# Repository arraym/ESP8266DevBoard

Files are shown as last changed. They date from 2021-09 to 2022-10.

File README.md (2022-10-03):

# **ESP8266DevBoard v1.1**

## Programming interface

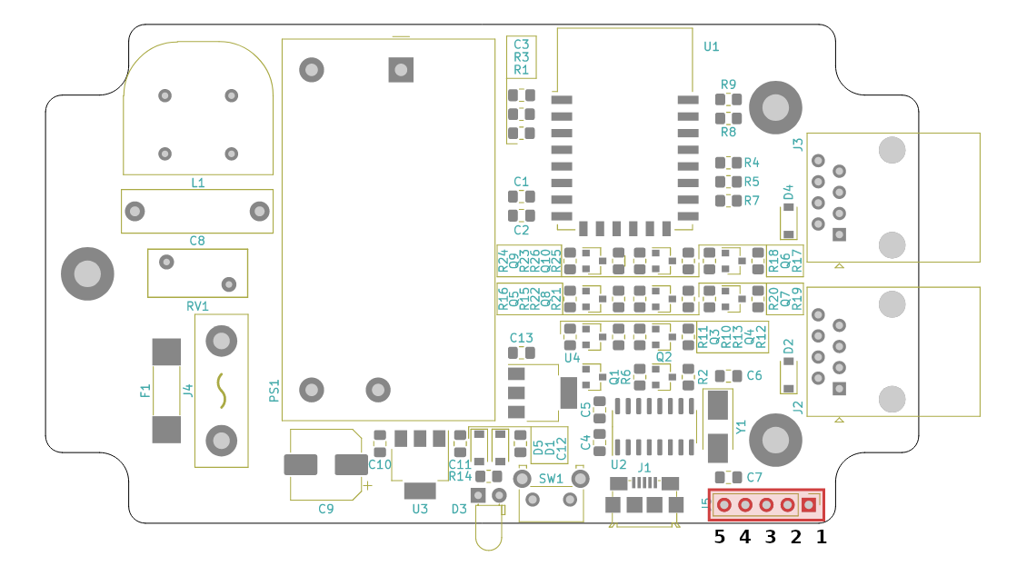
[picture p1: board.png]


The Serial UART interface is available at `J5` with the following pinout:

| Board Pin# | Signal | Required |
| --- | --- | --- |
| 1 | DTR | YES |
| 2 | RX | YES |
| 3 | TX | YES |
| 4 | RTS | YES |
| 5 | GND | YES |

For programming, all the pins marked as required must be connected.

**Remember to connect RX signal of the board to the RX signal of the programmer (same for TX).**

## Changelog

### **Changelog v1.1** ##
* J2, J3 (China RJ11 connectors) changed with RJ45 (MTJ-881X1)
* new LED and buzzer 12V controll lines added on each RJ45 connector

### **Changelog v1.2** ##
* J5 programming connector added (68001-420HLF)
* U2, Y1, C4, C5, C6, C7, D1, J1 set to DNP

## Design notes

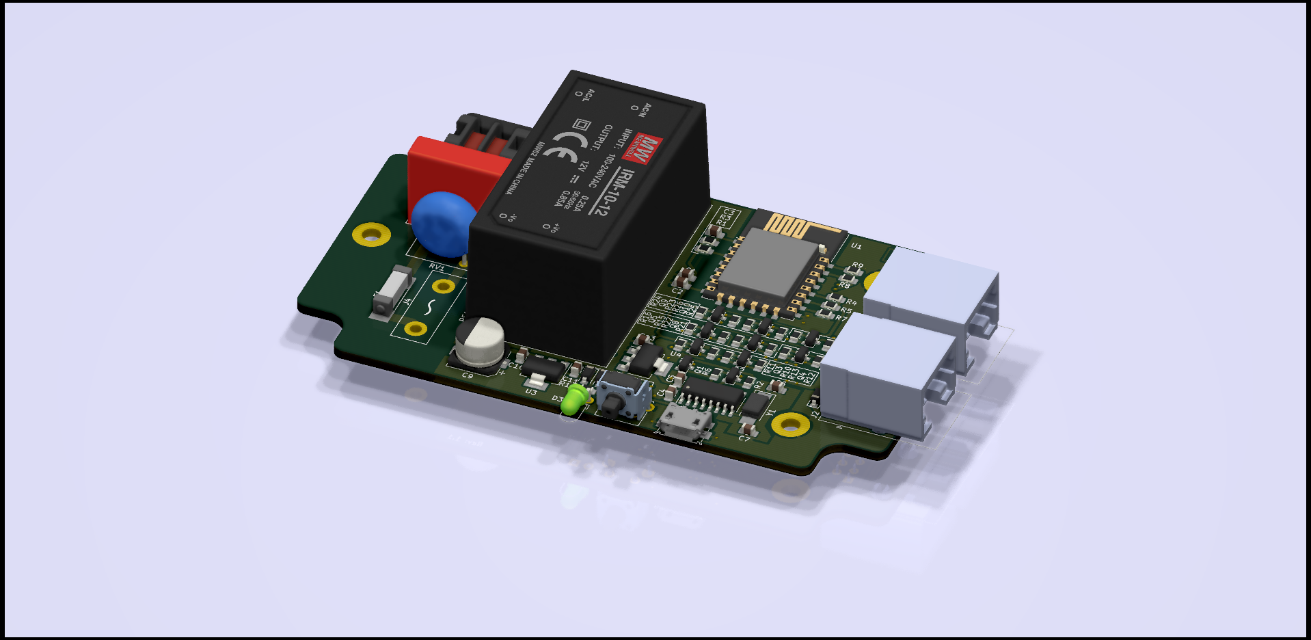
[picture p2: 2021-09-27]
ESP8266DevBoard.png

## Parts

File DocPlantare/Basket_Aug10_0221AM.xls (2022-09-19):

SHOPPING BASKET
This is not an invoice
10-Aug-21 02:21:33
 | Mouser No | Mfr. No | Manufacturer | Customer No | Description | RoHS | Lifecycle | Order Qty. | Price (RON) | Ext.: (RON)
1 | 647-UWX0J221MCL1 | UWX0J221MCL1GB | Nichicon |  | Aluminium Electrolytic Capacitors - SMD 6.3volts 220uF AEC-Q200 | RoHS Compliant |  | 6 | 1,56 RON | 9,36 RON
2 | 652-CR0805JW-471ELF | CR0805-JW-471ELF | Bourns |  | Thick Film Resistors - SMD 470ohm 5% | RoHS Compliant By Exemption |  | 20 | 0,092 RON | 1,84 RON
3 | 81-GRM21BC81C106KE5L | GRM21BC81C106KE15L | Murata |  | Multilayer Ceramic Capacitors MLCC - SMD/SMT 0805 10uF 16volts *Derate Voltage/Temp | RoHS Compliant |  | 25 | 0,737 RON | 18,43 RON
4 | 621-1N5819HWQ-7-F | 1N5819HWQ-7-F | Diodes Incorporated |  | Schottky Diodes & Rectifiers Schottky Rectifier | RoHS Compliant |  | 25 | 1,36 RON | 34,00 RON
5 | 815-ABM3-12-D2Y-T | ABM3-12.000MHZ-D2Y-T | ABRACON |  | Crystals 12.0 MHZ 18PF 60OHM | RoHS Compliant By Exemption |  | 6 | 2,71 RON | 16,26 RON
6 | 652-MOV-10D561K | MOV-10D561K | Bourns |  | Varistors 180pF 560volts 10% | RoHS Compliant |  | 6 | 0,698 RON | 4,19 RON
7 | 863-BC847BLT1G | BC847BLT1G | ON Semiconductor |  | Bipolar Transistors - BJT 100mA 50V NPN | RoHS Compliant |  | 12 | 0,587 RON | 7,04 RON
8 | 649-10118192-0001LF | 10118192-0001LF | FCI / Amphenol |  | USB Connectors 5P MICRO USB TYPE B RECEPTACLE | RoHS Compliant |  | 6 | 1,77 RON | 10,62 RON
9 | 80-C0805C104M5R | C0805C104M5RACTU | KEMET |  | Multilayer Ceramic Capacitors MLCC - SMD/SMT 50V 0.1uF X7R 0805 20% | RoHS Compliant |  | 30 | 0,16 RON | 4,80 RON
10 | 80-C0805C180M3HACTU | C0805C180M3HACTU | KEMET |  | Multilayer Ceramic Capacitors MLCC - SMD/SMT 25V 18pF X8R 0805 20% | RoHS Compliant |  | 12 | 0,31 RON | 3,72 RON
11 | 652-CR0805-JW-103ELF | CR0805-JW-103ELF | Bourns |  | Thick Film Resistors - SMD 10K 5% | RoHS Compliant By Exemption |  | 100 | 0,039 RON | 3,90 RON
12 | 80-SU9H-01100 | SU9H-01100 | KEMET |  | Common Mode Chokes / Filters 0.1amp 10mH | RoHS Compliant |  | 6 | 3,57 RON | 21,42 RON
13 | 693-3405.0165.24 | 3405.0165.24 | Schurter |  | Surface Mount Fuses UMF 250, 800mA 250 VAC, 125 VDC | RoHS Compliant |  | 6 | 2,71 RON | 16,26 RON
14 | 709-IRM10-12 | IRM-10-12 | MEAN WELL |  | AC/DC Power Modules 12V 0.85A 10.2W 85-264Vin Encap PS | RoHS Compliant |  | 3 | 38,07 RON | 114,21 RON
15 | 653-B3F-3152 | B3F-3152 | Omron |  | Tactile Switches R/A 6X6 6.15mm BTN | RoHS Compliant |  | 5 | 2,01 RON | 10,05 RON
16 | 863-LM1117MPX-33NOPB | LM1117MPX-33NOPB | ON Semiconductor |  | LDO Voltage Regulators LM ANA SOT223 800MA LDO |  | New Product | 6 | 2,43 RON | 14,58 RON
17 | 863-LM1117MPX-50NOPB | LM1117MPX-50NOPB | ON Semiconductor |  | LDO Voltage Regulators LM ANA SOT223 800MA LDO |  | New Product | 6 | 2,43 RON | 14,58 RON
18 | 485-2491 | 2491 | Adafruit |  | WiFi Development Tools - 802.11 ESP8266 SMT Module - ESP-12F | RoHS Compliant |  | 5 | 28,62 RON | 143,10 RON
19 | 726-2N7002H6327XTSA2 | 2N7002H6327XTSA2 | Infineon |  | MOSFET N-Ch 60V 300mA SOT-23-3 | RoHS Compliant |  | 25 | 0,912 RON | 22,80 RON
20 | 859-LTL-4231N | LTL-4231N | Lite-On |  | Standard LEDs - Through Hole Green Diffused | RoHS Compliant |  | 10 | 0,403 RON | 4,03 RON
21 | 80-R46KI310000M1K | R46KI310000M1K | KEMET |  | Safety Capacitors 275vac 0.1uF 10% | RoHS Compliant |  | 6 | 1,77 RON | 10,62 RON
By submitting your order you agree to these terms and conditions. (https://ro.mouser.com/saleterms) |  |  |  |  |  |  |  |  | Merchandise: | 485,81 RON
Prices are reflected at the date and time shown. |  |  |  |  |  |  |  |  | Delivery Charge: | 0,00 RON

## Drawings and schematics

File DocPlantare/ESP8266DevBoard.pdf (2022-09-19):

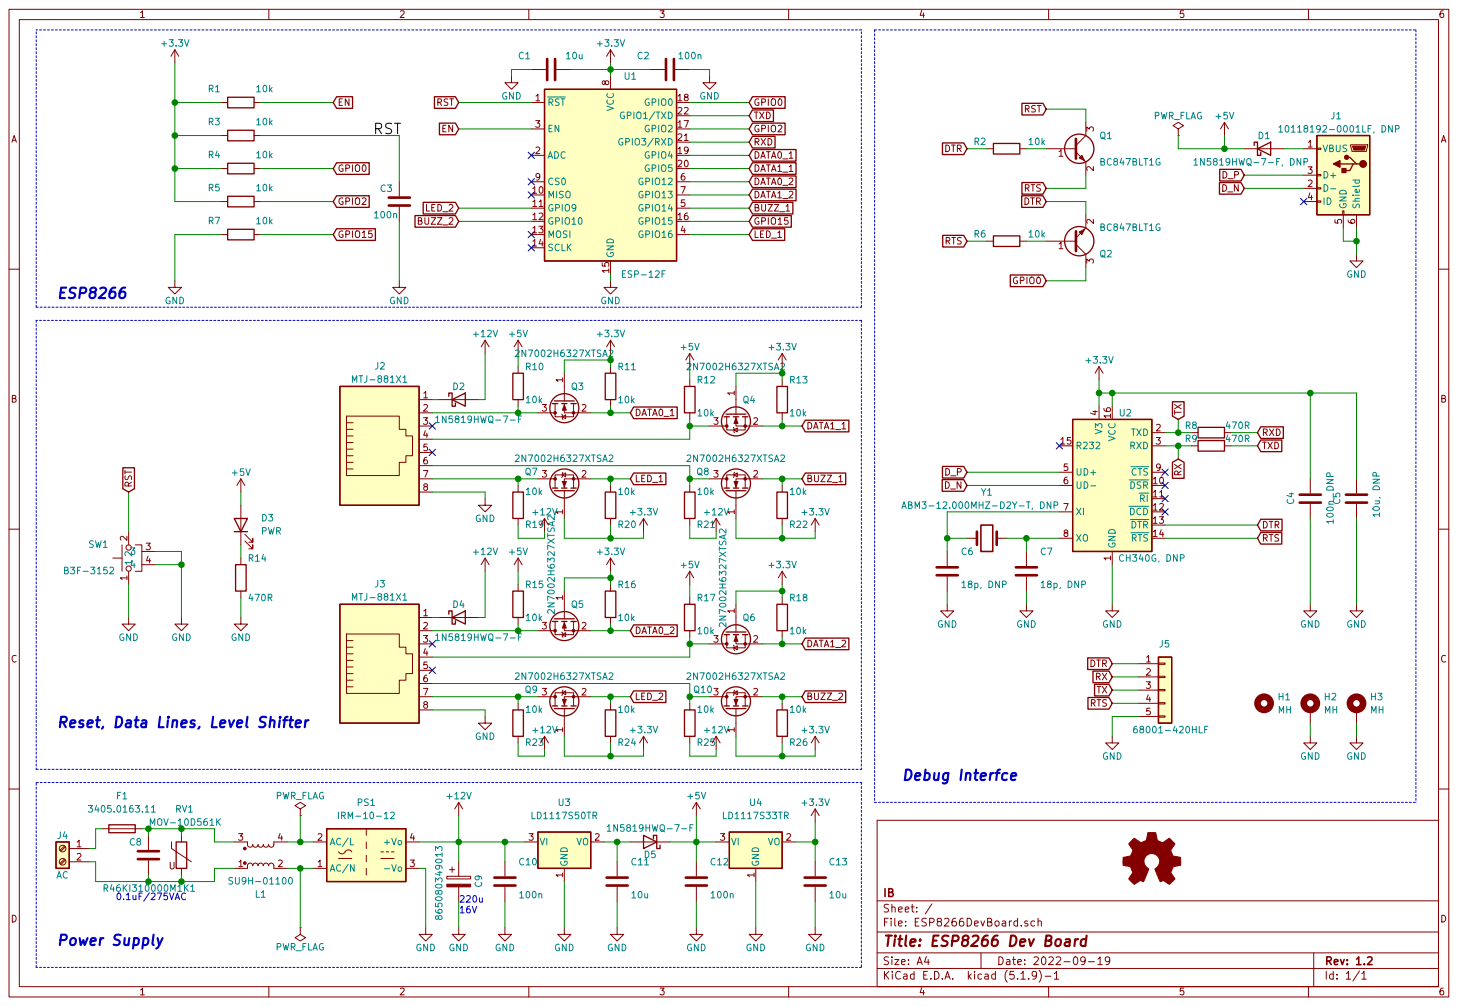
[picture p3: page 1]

1 DSR 10 RI 11 DCD 12 DTR 13 RTS 14 R232 15 VCC 16 TXD 2 RXD 3 V3

4 UD+ 5 UD- 6 XI 7 XO 8 CTS 9 U2CH340G, DNP

Reset, Data Lines, Level Shifter

File: ESP8266DevBoard.sch Sheet: /
Id: 1/1 Title: ESP8266 Dev Board

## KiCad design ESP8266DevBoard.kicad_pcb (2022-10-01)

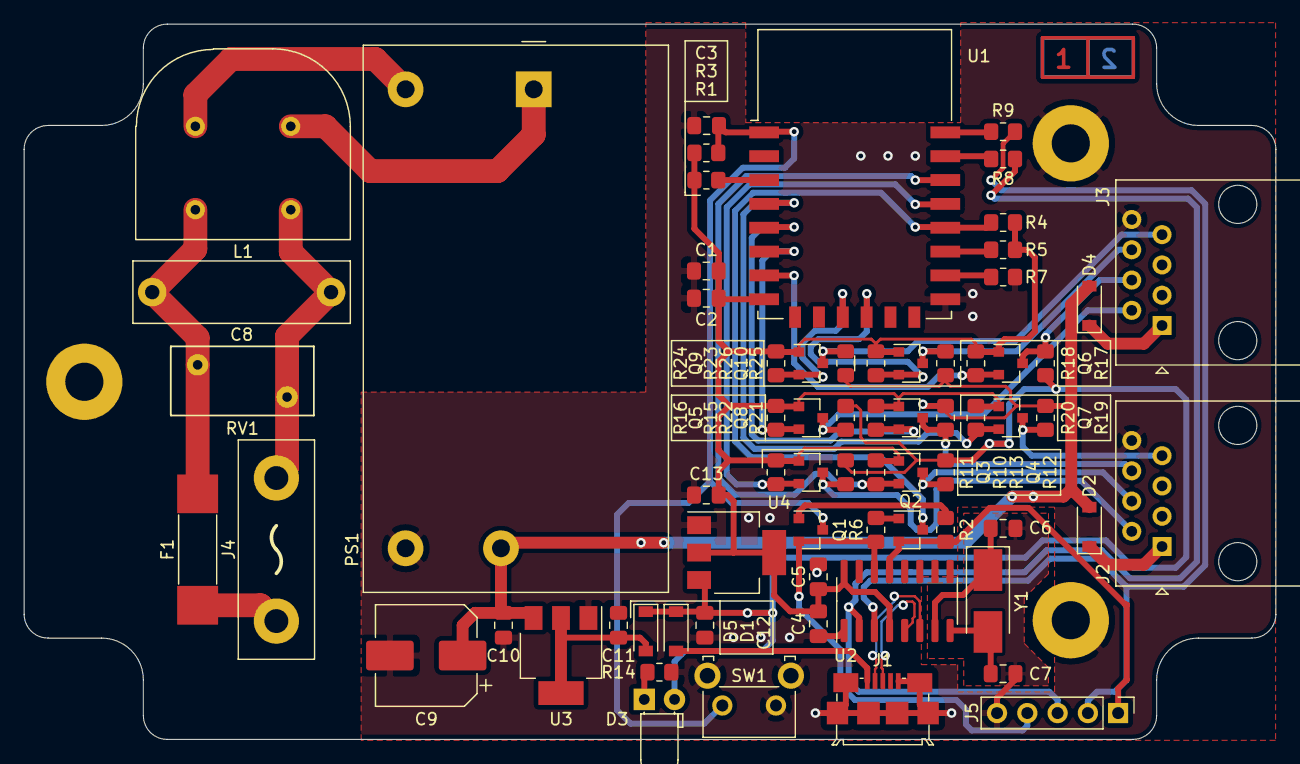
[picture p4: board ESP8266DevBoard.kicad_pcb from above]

Board: 2 copper layers, 105.0 x 60.0 mm, 72 parts (0 on the bottom side), 47 nets.

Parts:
C1, C11, C13: 10u; C_0805_2012Metric_Pad1.18x1.45mm_HandSolder
C2, C3, C10, C12: 100n; C_0805_2012Metric_Pad1.18x1.45mm_HandSolder
C4: 100n, DNP; C_0805_2012Metric_Pad1.18x1.45mm_HandSolder
C5: 10u, DNP; C_0805_2012Metric_Pad1.18x1.45mm_HandSolder
C6, C7: 18p, DNP; C_0805_2012Metric_Pad1.18x1.45mm_HandSolder
C8: R46KI310000M1K1; C_Rect_L18.0mm_W5.0mm_P15.00mm_FKS3_FKP3
C9: 865080349013; CP_Elec_8x5.4
D1: 1N5819HWQ-7-F, DNP; D_SOD-123
D2, D4, D5: 1N5819HWQ-7-F; D_SOD-123
D3: PWR; LED_D3.0mm_Horizontal_O1.27mm_Z2.0mm
F1: 3405.0163.11; Fuse_10x3mm
H1, H2, H3: MH; MountingHole_3.2mm_M3_Pad
J1: 10118192-0001LF, DNP; USB_Micro-B_Amphenol_10118192-0001LF_Horizontal
J2, J3: MTJ-881X1; RJ45_Multicomp_MTJ-881X1_Horizontal
J4: AC; AC_Connector_2x2mm_P12mm
J5: 68001-420HLF; PinHeader_1x05_P2.54mm_Vertical
L1: SU9H-01100; L_SU9H
PS1: IRM-10-12; Converter_ACDC_MeanWell_IRM-10-xx_THT
Q1, Q2: BC847BLT1G; SOT-23
Q3, Q4, Q5, Q6, Q7, Q8, Q9, Q10: 2N7002H6327XTSA2; SOT-23
R1, R2, R3, R4, R5, R6, R7, R10, R11, R12, R13, R15, R16, R17, R18, R19, R20, R21, R22, R23, R24, R25, R26: 10k; R_0805_2012Metric_Pad1.20x1.40mm_HandSolder
R8, R9, R14: 470R; R_0805_2012Metric_Pad1.20x1.40mm_HandSolder
RV1: MOV-10D561K; RV_Disc_D12mm_W5.8mm_P7.5mm
SW1: B3F-3152; SW_Tactile_SKHH_Angled
U1: ESP-12F; ESP-12E
U2: CH340G, DNP; SOIC-16_3.9x9.9mm_P1.27mm
U3: LD1117S50TR; SOT-223-3_TabPin2
U4: LD1117S33TR; SOT-223-3_TabPin2
Y1: ABM3-12.000MHZ-D2Y-T, DNP; Crystal_SMD_5032-2Pin_5.0x3.2mm_HandSoldering

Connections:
+3V3: C1.2, C2.1, C4.1, C5.1, C13.1, Q3.1, Q4.1, Q5.1, Q6.1, Q7.1, Q8.1, Q9.1, Q10.1, R1.1, R3.1, R4.1, R5.1, R11.1, R13.1, R16.1, R18.1, R20.1, R22.1, R24.1, R26.1, U1.8, U2.4, U2.16, U4.2
+5V: C12.1, D1.1, D3.2, D5.1, R10.1, R12.1, R15.1, R17.1, U4.3
+12V: C9.1, C10.1, D2.2, D4.2, PS1.4, R19.1, R21.1, R23.1, R25.1, U3.3
BUZZ_1: Q8.2, R22.2, U1.5
BUZZ_2: Q10.2, R26.2, U1.12
DATA0_1: Q3.2, R11.2, U1.19
DATA0_2: Q5.2, R16.2, U1.6
DATA1_1: Q4.2, R13.2, U1.20
DATA1_2: Q6.2, R18.2, U1.7
DTR: J5.1, Q2.2, R2.1, U2.13
D_N: J1.2, U2.6
D_P: J1.3, U2.5
EN: R1.2, U1.3
GND: C1.1, C2.2, C3.2, C4.2, C5.2, C6.2, C7.2, C9.2, C10.2, C11.2, C12.2, C13.2, H2.1, H3.1, J1.5, J1.6, J2.8, J3.8, J5.5, PS1.3, R7.1, R14.2, SW1.1, SW1.3, SW1.4, U1.15, U2.1, U3.1, U4.1
GPIO0: Q2.3, R4.2, U1.18
GPIO2: R5.2, U1.17
GPIO15: R7.2, U1.16
LED_1: Q7.2, R20.2, U1.4
LED_2: Q9.2, R24.2, U1.11
unnamed: C6.1, U2.7, Y1.1
unnamed: C7.1, U2.8, Y1.2
unnamed: C8.1, F1.1, L1.3, RV1.1
unnamed: C8.2, J4.2, L1.1, RV1.2
unnamed: C11.1, D5.2, U3.2
unnamed: D1.2, J1.1
unnamed: D2.1, J2.1
unnamed: D3.1, R14.1
unnamed: D4.1, J3.1
unnamed: F1.2, J4.1
unnamed: J2.2, Q3.3, R10.2
unnamed: J2.4, Q4.3, R12.2
unnamed: J2.6, Q8.3, R21.2
unnamed: J2.7, Q7.3, R19.2
unnamed: J3.2, Q5.3, R15.2
unnamed: J3.4, Q6.3, R17.2
unnamed: J3.6, Q10.3, R25.2
unnamed: J3.7, Q9.3, R23.2
unnamed: L1.2, PS1.1
unnamed: L1.4, PS1.2
unnamed: Q1.1, R2.2
unnamed: Q2.1, R6.2
RST: C3.1, Q1.3, R3.2, SW1.2, U1.1
RTS: J5.4, Q1.2, R6.1, U2.14
RX: J5.2, R9.1, U2.3
RXD: R8.2, U1.21
TX: J5.3, R8.1, U2.2
TXD: R9.2, U1.22

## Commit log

2021-08-03 Initial commit.
    [ESP8266DevBoard.kicad_pcb, ESP8266DevBoard.sch]
2021-08-04 5V LDO added, second level shifter, board outline done.
    [ESP8266DevBoard.kicad_pcb, ESP8266DevBoard.sch]
2021-08-06 3mm LED added to schematic, footprints assigned.
    [ESP8266DevBoard.kicad_pcb, ESP8266DevBoard.sch]
2021-08-07 Components placed on the board.
    [ESP8266DevBoard.kicad_pcb, ESP8266DevBoard.sch]
2021-08-07 Routing done.
    [ESP8266DevBoard.kicad_pcb, ESP8266DevBoard.sch]
2021-08-08 PCB routing done, gerber files added.
    [ESP8266DevBoard-B_Cu.gbr, ESP8266DevBoard-B_Mask.gbr, ESP8266DevBoard-B_Paste.gbr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]
2021-08-10 Mouser components basket added.
    [Basket_Aug10_0221AM.xls]
2021-09-19 Board corners fixed to match plastic case, all corners counded.
    [ESP8266DevBoard.kicad_pcb]
2021-09-24 RJ connectors changed, LED and buzzer controll lines added for each conector, readme file with rev changes added.
    [ESP8266DevBoard.kicad_pcb, ESP8266DevBoard.sch]
2021-09-27 Routing done, gerber files added (v1.1).
    [ESP8266DevBoard-B_Cu.gbr, ESP8266DevBoard-B_Mask.gbr, ESP8266DevBoard-B_Paste.gbr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]
2022-09-19 Programming connector added, gerber files generated (v1.2).
    [Basket_Aug10_0221AM.xls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]
2022-10-01 DNP components removed from paste file, programming connector silk added, paste and silk gerbers regenerated, new ibom file generated.
    [ESP8266DevBoard.kicad_pcb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]
2022-10-03 README.md: updated with UART pinout
